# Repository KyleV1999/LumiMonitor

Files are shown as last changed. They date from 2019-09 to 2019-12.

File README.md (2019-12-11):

# PIR Motion Sensor Build Instructions for the LumiMonitor

## Table of Contents
* [Introduction](https://github.com/KyleV1999/LumiMonitor#Introduction)
* [Budget](https://github.com/KyleV1999/LumiMonitor#Budget)
* [Time Commitment](https://github.com/KyleV1999/LumiMonitor#Time-Commitment)
* [Setting Up Your Platform](https://github.com/KyleV1999/LumiMonitor#Setting-Up-Your-Development-Platform)
* [Mechanical Assembly](https://github.com/KyleV1999/LumiMonitor#Mechanical-Assembly)
* [PCB Soldering](https://github.com/KyleV1999/LumiMonitor#PCB-Soldering)
* [Case](https://github.com/KyleV1999/LumiMonitor#Case)
* [Power Up](https://github.com/KyleV1999/LumiMonitor#Power-Up)
* [Production Testing](https://github.com/KyleV1999/LumiMonitor#Production-Testing)

## Introduction

This is the build instructions for building the PIR Motion sensor as part of the LumiMonitor project. The PIR (Passive Infared) Motion Sensor will detect motion within 3 meters of the sensor. These instuction will show you how to design and build the breadboard and PCB circuits to intigrate the sensor with a Broadcom Development Platform (Raspberry Pi 3B+). I will also provide a list of materials and links to where you can buy them, as well as a Corel Draw file so that you can laser cut a case out of clear acrylic. These instutions take into account that you will have access to equipment such as a soldering iron, laser cutter, wire strippers, etc. The PIR Motion Sensor will be used in the final Lumi Monitor project to intiate hands-free data collection. The photo below depicts the final product:

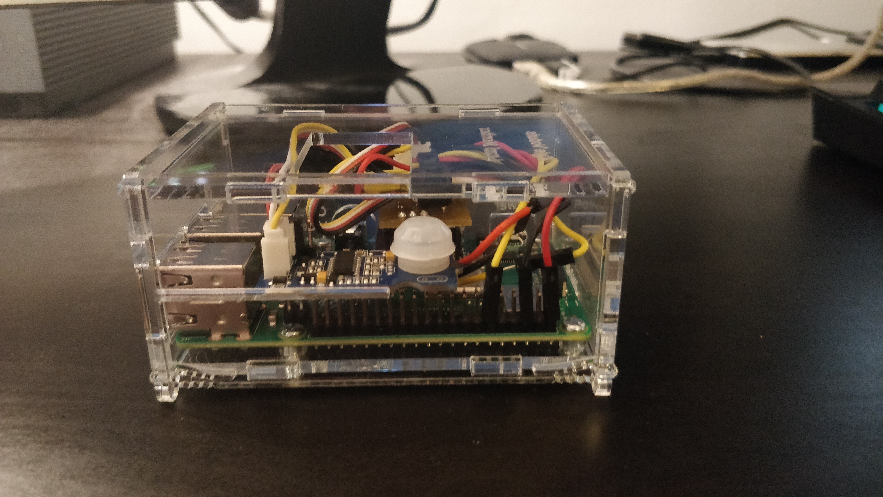
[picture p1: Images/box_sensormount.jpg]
Final Product


### System Diagram

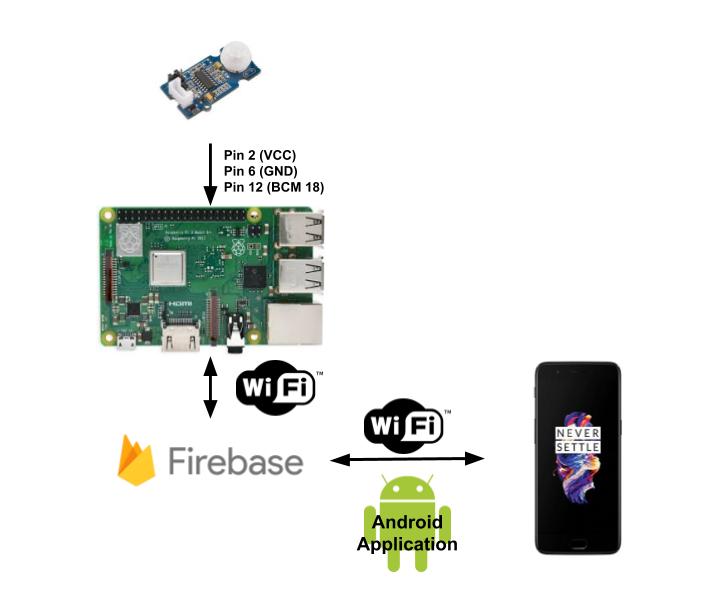
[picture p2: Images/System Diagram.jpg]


Before you begin some skills you will need duing the build of this project include:
* Basic electrical and circuit knowledge
* Basic programming knowledge
  * This project specifically was programmed in Python
* Basic understanding of the Raspberry Pi and Linux based operating systems
* Soldering

## Budget
Thse are the parts needed to complete the project. Displayed below are links and price breakdown for each component.

### Parts for Lumi Monitor

| Part | Source  | Part Number | # of Units | Price Per Unit (CAD)  | Taxes & Shipping (CAD) | Subtotal  | Link |
| --- | --- | --- | --- | --- | --- | --- | ---- |
| Raspberry Pi 3 B+ Motherboard | Amazon | 3BPLUS-R | 1 | $55.97 | $7.28 | $63.25 | https://amzn.to/2kMYDtb |
| Grove ‐ PIR Motion Sensor | Digikey | 101020020 | 1 | $11.56 | $8.35 | $19.91 | https://bit.ly/2kKx8QV | 
| Seeedstudio Grove 4-pin Connector (10) | robotshop.com | RB-See-204 | 1 | $1.33 | $9.01 | $11.67 | https://bit.ly/32it9vh |
| Breakaway PCB Board Header Connector | Amazon | ODYF162934WAZR85384 | 1 | $12.80 | $4.18 | $16.98 | https://amzn.to/37IDlAd |
| Elegoo 120pcs Multicolored Dupont Wire | Amazon | EL-CP-004 | 1 | $11.95 | $4.36 | $16.31 | https://amzn.to/2qHYRop |
| Kingston 32 GB Micro SD Card | Walmart | SDCS/32GBCR | 1 | $11.98 | $2.98 | $14.96 | https://bit.ly/2souG61 / In Store |
| AmazonBasics USB 3.0 to Ethernet Adapter | Amazon | AE3101X1 | 1 | $20.05 | $4.53 | $24.58 | https://amzn.to/2Nwrq0A |
| 3ft Ethernet Cable| PrimeCables.ca | | 1 | $1.24 | $6.88 | $8.12 | https://bit.ly/2QYcxGe |
| Raspberry Pi Micro USB Power Supply | Amazon |DCAR-RSP-2A5 | 1 | $11.99 | $6.36 | $18.35 | https://amzn.to/2skohZp |
| Clear Acrylic Glass 3mm | Amazon | | 1 | $17.09 | $0.00 | $17.09 | https://amzn.to/2XWM1OX |
| M2.5 Screws | Digikey | | 4 | $0.15 | $0.00 | $0.60 | https://bit.ly/2Oy8TS9 |
| Lead Free Solder | Amazon | 2-CA-X | 1 | $15.99 | $4.32 | $20.31 | https://amzn.to/37JXLJj |
| **Total Cost** | **$232.13** |
| **Total Tax & Shipping** | **$58.25** | 

It would also be a good idea to have your PCB made and your case laser cut before you start your project. Use this [fritzing file](Electronics/LumiMonitor_MotionSensor2.fzz) to generate your gerber file and this [corel draw](Mechanical/KylePi2CaseX6.cdr) file to have your case cut.

Here is the link to [seeedstudio.com/](https://www.seeedstudio.com/fusion_pcb.html) where you can upload your gerber file  to have your PCB made. It is $3.92USD ($5.19 CAD) for 10 PCBs.

**Below is an image that contains all the major parts for the project; The Grove PIR Motion Sensor, Raspberry Pi 3B+ and Grove Sockets.**

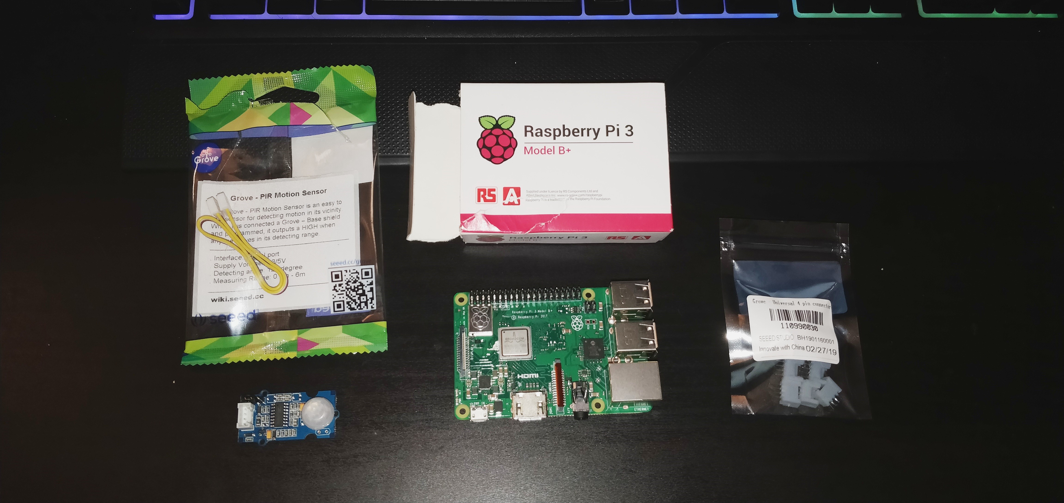
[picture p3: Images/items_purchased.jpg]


## Time Commitment

When I put together this project, I did it in a period of 14 weeks. The schedual that I followed to complete the project is shown below. However, this project can most likely be done in the matter of a weekend, granted that all the parts needed have been delivered, you have your PCB made and that you have access to all the required equipment needed to complete the project.

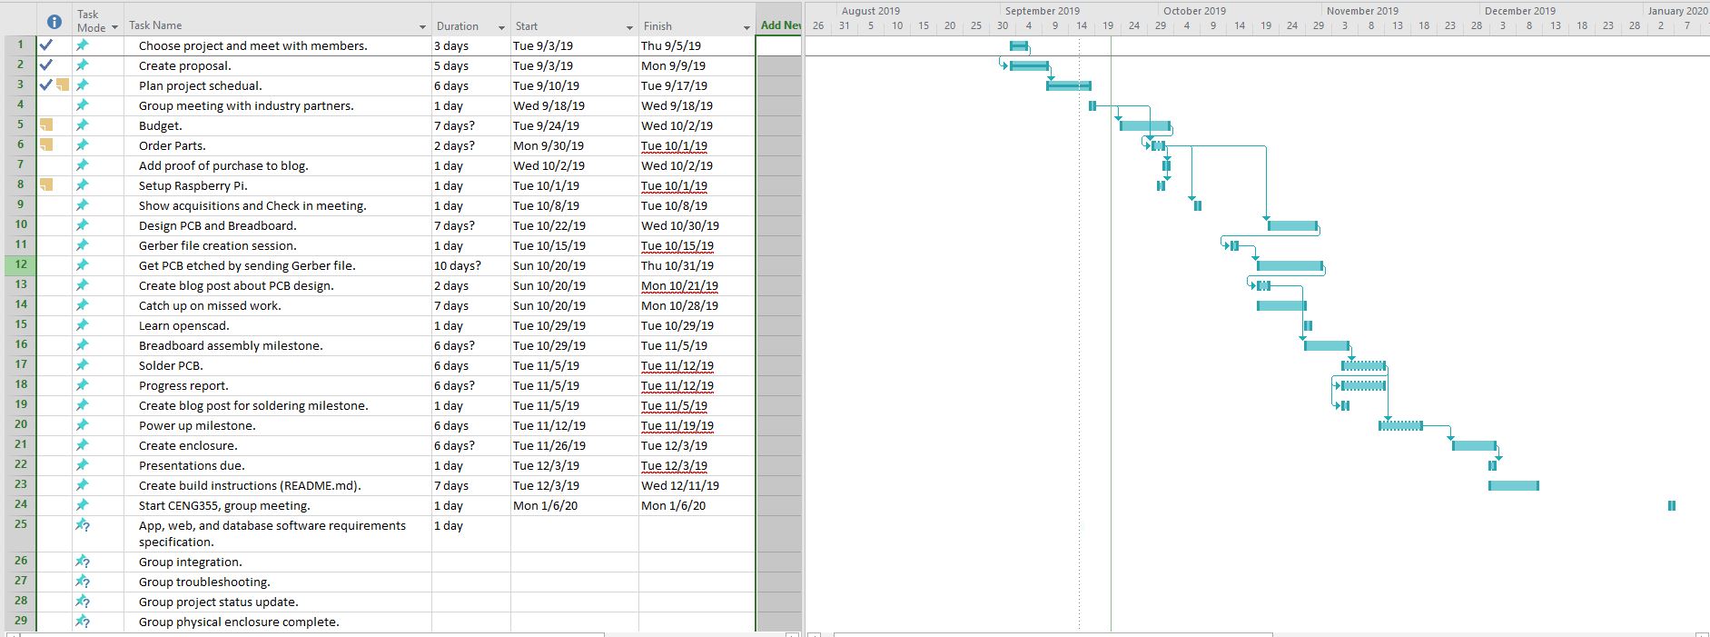
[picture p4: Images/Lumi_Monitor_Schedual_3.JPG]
Schedual


**Estimate Time:**

* Setting up your development platform - 45 Minutes
* Breadboard Assembly & Testing - 25 Minutes
* PCB Soldering - 30 Minutes
* PCB Powerup - 5 Minutes
* Laser Cut Case - 20 Minutes
* Assemble Case w/ Development Platform & Sensor - 25 Minutes
* Final Testing & Troubleshooting - 20 Minutes

**Total Estimated Time: 170 Minutes or 2 Hours and 50 Minutes**

## Setting Up Your Development Platform
The very first step of the project would be to setup your Raspberry Pi 3B+ with the latest kernal of Raspian. If you are new to Raspberry Pi's, I would reccommend doing this through NOOBS (New Out Of the Box Software) operating system installer. I've made this tutorial video on how to do this: [How To Install NOOBS Onto A Raspberry Pi (3B+/4)](https://youtu.be/TlQxaEdyBgM).

### Setting Up SSH

Once your Raspberry Pi has been configured with an operating system, remote desktop and SSH should be configured so that you can connect to the Pi through USB to Ethernet rather than displaying the Pi on a external display through an HDMI cable. 

To setup SSH, begin by opening the terminal by pressing CTRL+ALT+T on the keyboard. Next, use the command ```sudo raspi-config```. An interface similar to as show below should appear. Using the up and down arrow keys select interfacing options and press ENTER.

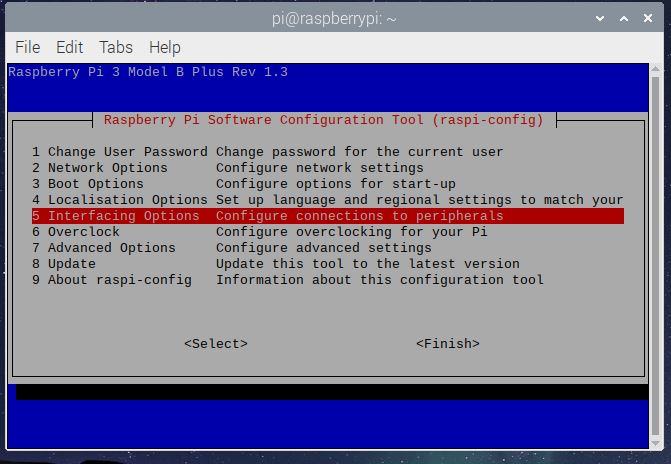
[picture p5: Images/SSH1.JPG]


Next, use the up and down arrow keys to select SSH and hit enter.

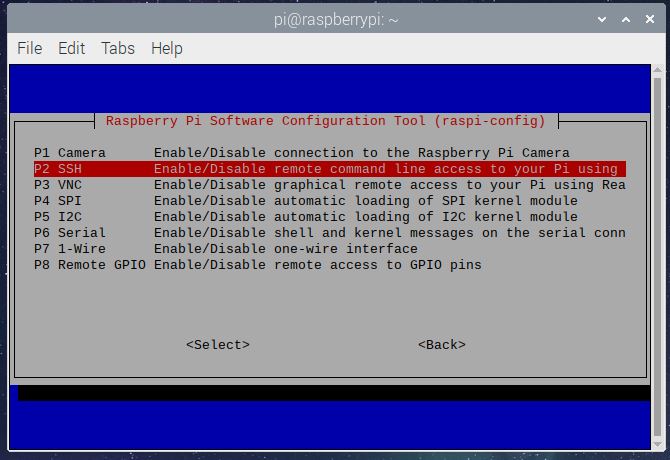
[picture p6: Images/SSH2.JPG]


Finally, using the right and left arrow keys select Yes. SSH has now been successfully enabled.

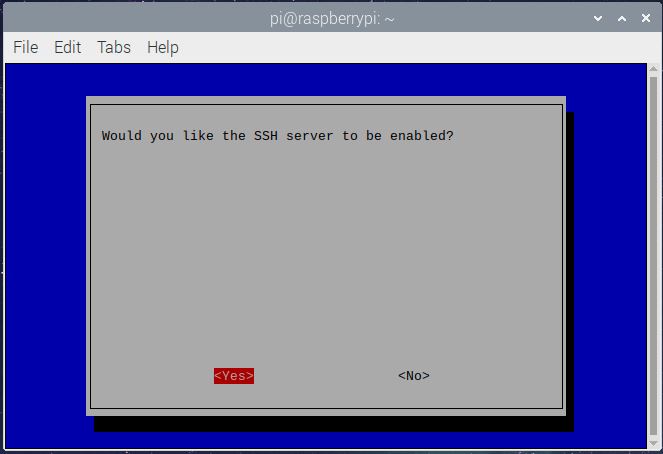
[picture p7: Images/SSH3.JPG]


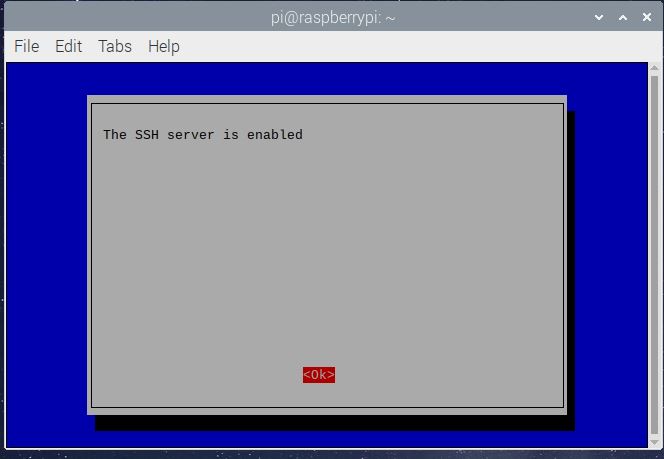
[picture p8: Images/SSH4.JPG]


Now, plug in one end of the ethernet cable into the Raspberry Pi and the other end into the adapter. Plug the USB end of the adapter into a PC. Next use the ```ifconfig``` command to retrieve the IPv4 address of the Pi's ethernet interface. In my case it is 169.254.123.117.

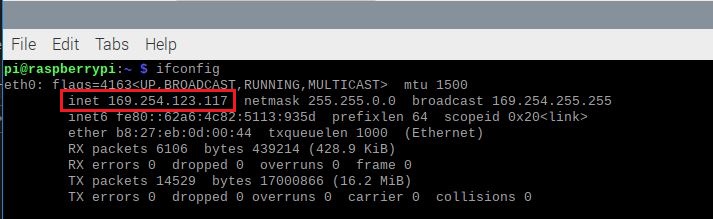
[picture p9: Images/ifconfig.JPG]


Now use and SSH client like [PuTTY](https://www.chiark.greenend.org.uk/~sgtatham/putty/latest.html). Enter the IPv4 address then press open. You should be prompted with a login. Enter your Pi's username and password. Finally, you should be able to control the terminal of your Raspberry Pi through SSH.

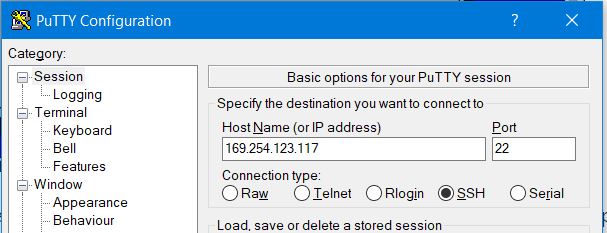
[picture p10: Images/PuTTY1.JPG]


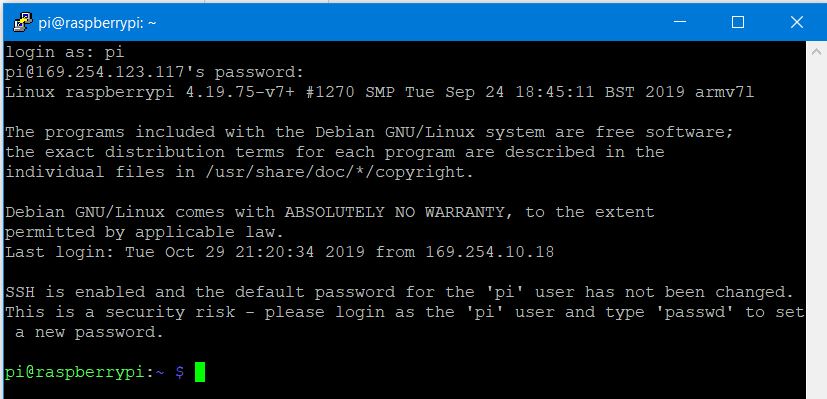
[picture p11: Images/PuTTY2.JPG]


### Setting Up Remote Desktop
To enable remote desktop to connect and control the Raspberry Pi with a graphical user interface, open up the terminal on the Pi and enter the following commands:

```sudo apt-get install tightvncserver```

```sudo apt-get install xrdp```

After that make sure that your Raspberry Pi is connected to a PC with the ethernet cable and USB to ethernet adapter. Now open "Remote Desktop" on the PC and put in the IPv4 address found earlier and click connect. Enter your Pi's login information and finally, you should be in the remote desktop environment.

<img src="Images/RD1.PNG" align="center">

<img src="Images/RD2.PNG" width="720" height="400" align="center">

<img src="Images/RD3.PNG" width="720" height="500" align="center">

## Mechanical Assembly
Now that your development platform has been setup, you should have your PCB made. Provided below are two [fritzing](https://fritzing.org/home/) files:

[Fritzing File With Development Platform](Electronics/LumiMonitor_MotionSensor.fzz)

[Fritzing File With Headers](LumiMonitor_MotionSensor2.fzz)

[Fritzing File With Development Platform](Electronics/LumiMonitor_MotionSensor.fzz) is the breadboard pictorial, schematic diagaram and PCB diagram that describes the connection between the sensor and the development platform. [Fritzing File With Headers](LumiMonitor_MotionSensor2.fzz) shows the connections with the header. Use this file to generate a Gerber file which is to be used to make your PCB.

Before you start soldering the PCB, it would be a good idea to test out that your components and development platform are functioning correctly by building the circuit on a breadboard. Below is and image of the breadboard pictorial and schematic diagram of the circuit.

![Breadboard](Images/LumiMonitor_MotionSensor_bb.jpg)

<img src="Images/LumiMonitor_MotionSensor_schem.jpg" width="720" height="500" align="center">

One thing to keep in mind when breadboarding is that the pins on the Grove socket, for the motion sensor, are too close together to fit on the breadboard. To get around this, stick wires directly into the header of the sensor's wire, then place each wire individually onto the breadboard. 

* Pin 2 (5V) of the Raspberry Pi should be connected to the positive side of the breadboard.
* Pin 6 (GND) of the Raspberry Pi should be connected to the negative side of the breadboard.
* The red (VCC) wire from the motion sensor should be connected to the positive side of the breadboard.
* The black (GND) wire from the motion sensor should be connected to the negativeside of the breadboard.
* The yellow (D1) wire from the motion sensor should be connected to breadboard.
* Pin 12 (BCM 18) of the Raspberry Pi should be connected to the D1 from the sensor on the breadboard.

[pinout.xyz](https://pinout.xyz/) is a good reference for the Raspberry Pi's pin layout. When you finish breadboarding, it should look something like the image below.

![Breadboard](Images/breadboard1.jpg)

Now test to see if the motion sensor is working. [Upload this code to your Pi](Software/motion.py). This is a Python script which will detect HIGH (if motion is detected) and LOW (if no motion is detected). To run the code, open the terminal and make sure that you are in the same directory as your code. Use the command ```python motion.py``` to run the script. If motion is detected, "Motion detected" should be printed out on the screen. If no motion is detected then "No motion detected" is printed. When the sensor detects motion it will stay in a HIGH state for 1 second.

<img src="Images/ScreenCapture2.JPG" width="720" height="400" align="center">

## PCB Soldering

If this is your first time soldering, I would recommend that you watch this tutorial before you begin: [Beginner how to Solder](https://www.youtube.com/watch?v=oqV2xU1fee8). Below is a PCB Diagram from fitzing along with images of the front and back sides of the PCB before anything is soldered.

<img src="Images/LumiMonitor_MotionSensor_pcb2.jpg" align="center">

### Front of PCB
<img src="Images/pcb_front_cropped.jpg" width="720" height="480" align="center">

### Back of PCB
<img src="Images/pcb_back_cropped.jpg" width="720" height="480" align="center">

1. The first step in soldering the PCB would be to solder the female header. For this project you only need three sockets to connect to the Pi. Before soldering cut the longer header into three sockets with an exacto knife. The pins of the header should be soldered facing the front of the PCB.

1. Next, Solder the Grove socket to the PCB. The pins of the socket should be facing the bottom on the PCB.

1. Finally, you will need to solder the via's / through holes to connect the front side of the board to the back. This can be done by stripping a wire and applying solder to both sides of the hole. 

An example of the final product is shown below:

### Front

<img src="Images/pcb_front_soldered_cropped.jpg" width="750" height="750" align="center">

### Back

<img src="Images/pcb_back_soldered.jpg" width="600" height="1000" align="center">

### With Sensor Connected

<img src="Images/pcb_soldered_sensor_cropped.jpg" width="800" height="550" align="center">

## Case

Here is a link to the [Corel Draw](Mechanical/KylePi2CaseX6.cdr) file that will be used to lase cut the case. This is a modified design from which the original design can be found [here](https://github.com/diy-electronics/raspberrypi-b-plus-case).

Two slits were made, which is used to slide in the PCB and sensor to keep them in place. A window was also placed a the top to make it easier for the sensor to detect motion. There are screw holes at the bottom of the case to keep the development platform in place and all I/O are accessable.

<img src="Images/box_top_cropped.jpg" width="800" height="600" align="center">

## Power Up

Before you enclose your PCB and sensor into the case, It would be a good idea to power it up to see if your PCB soldering was successful. It is easier to do this outside of the case to make adjustments if needed. Plug the VCC, GND and D1 wires from the female socket on the PCB intro their correct pins on the Raspberry Pi and and plug the sensor into it's socket. Power up the Raspberry Pi and connect to it via SSH. Run the same code from before with the command ```python motion.py```. If everything is working correctly then "Motion Detected" will be displayed when motion is detected. **Warning do not leave the powered up project unattended just in case something goes wrong!** Finally, Once everything has been testedd and is working correctly, enclose you project in the case.

## Production Testing
When testing in a production environment, a PCB should be made for testing the sensor. This is because the dedicated socket for my sensor will not fit on a breadboard and it's simpiler and quicker to just plug the sensor into the socket to test it. Also a dedicated Raspbarry Pi with the all the software installed should be on hand. This is so any PCB or sensor can be swiftly connected, and tested in a matter of a few minutes.   

[Back To Top](https://github.com/KyleV1999/LumiMonitor#pir-motion-sensor-build-instructions-for-the-lumimonitor)

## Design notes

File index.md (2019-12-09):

<html>
<center><h1>Blog For CENG 317 - Lumi Monitor</h1></center>
	
<h2>Build Instructions - 10/12/2019</h2>
<p>Build instuctions for project are complete. <a href="https://github.com/KyleV1999/LumiMonitor/blob/master/README.md">Can be viewed here.</a></p>
	
<h2>Presentation - 25/11/2019</h2>
<p>The final presentation was due this week. <a href="Documentation/Lumi Monitor – PIR Motion Sensor.pptx">Here is a link to the slides from my repository.</a></p>
	
<h2>Enclosure - 18/11/2019</h2>
<p>Over the pass few days I have designed, laser cut and put together an enclosure, that is made out of clear acrylic, to incase my Raspberry Pi, PCB and sensor securely. I decided to use laser cutting to create my enclosure over 3D printing due to time constraints and designing a box for laser cutting is slightly easier. There were a few problems that I encountered while going though the process of making the enclousure. First of which was my lack of knowledge and skill in design. Since this was my first time doing a design project like this, I had to take some time to learn the design software (Corel Draw) and figure out how I was going to make my design so that it can incase all my components as securly as possible. I went to the Prototype Lab for help and the technologists suggested that I make modifications to an already made design. The original design can be found <a href="https://github.com/diy-electronics/raspberrypi-b-plus-case"><u>here</u></a>. This desgin is under a creative commons license therefore it can be used for free as long as credit is given to the original creator. The CC license is etched onto the bottom of the box. The second problem I ran into was the high demand for the laser cutter. It was hard to work around my schedule when the cutter was free. The demand was high due to the amount of final projects being cut on the cutter. Also the other laser cutters in the college have broken down, so the only laser cutter available was the one in the prototype lab, that was under high use. The changes that I made to the orignal case design was adding two slits on the side on the enclosure to slide my PCB and Sensor into to hold them in place. The height of the slits were mesaure as the same as the PCB's. This idea worked very well dispite what I originally thought and the PCB and sensor are securely in place. The next modification I made was making a hole at the top of the case so that my sensor can detect motion without the acrylic being in the way. Once the case was together I secured all wires with a zip tie and put them off to the side. The project is a few days ahead of schedule and no further additions to the budget have been made. The enclousure was one of the final big milestones for this term. The next step is to work on the Prototype Acceptance Presentation.</p> <a href="Mechanical/KylePi2CaseX6.cdr"><u>Here is a link to the corel draw file for my design.</u></a>
<br><br>
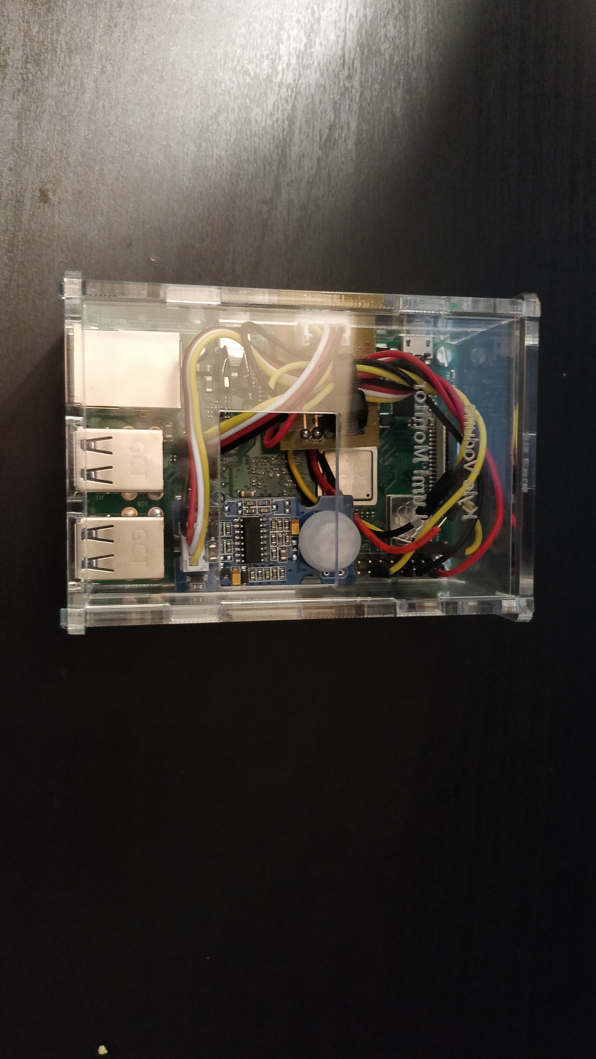
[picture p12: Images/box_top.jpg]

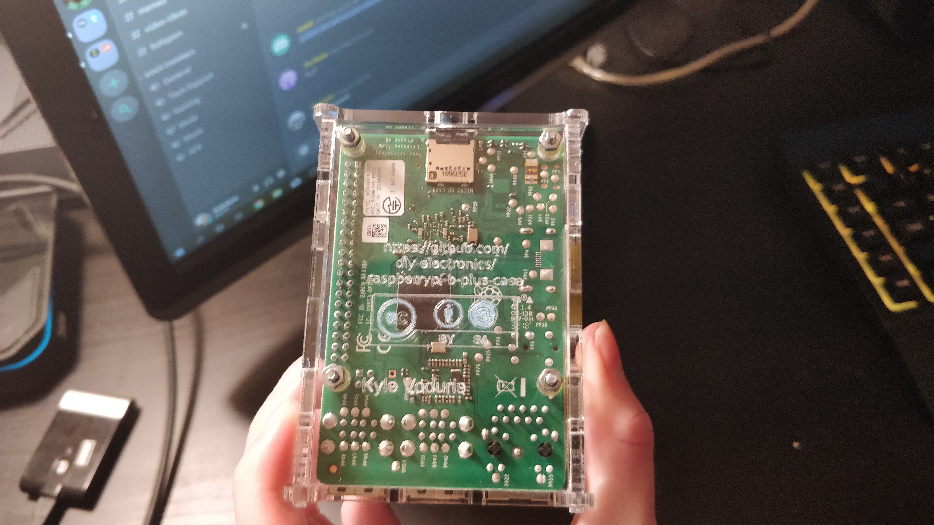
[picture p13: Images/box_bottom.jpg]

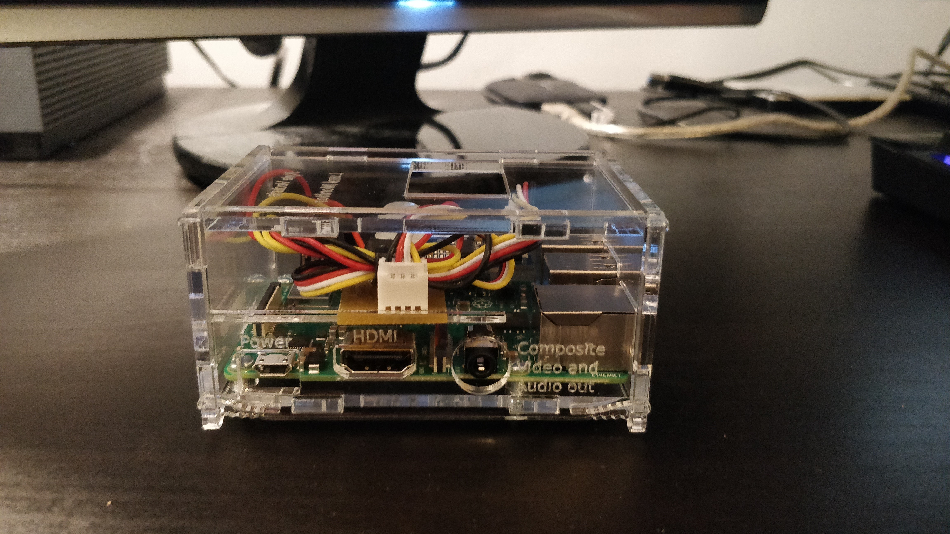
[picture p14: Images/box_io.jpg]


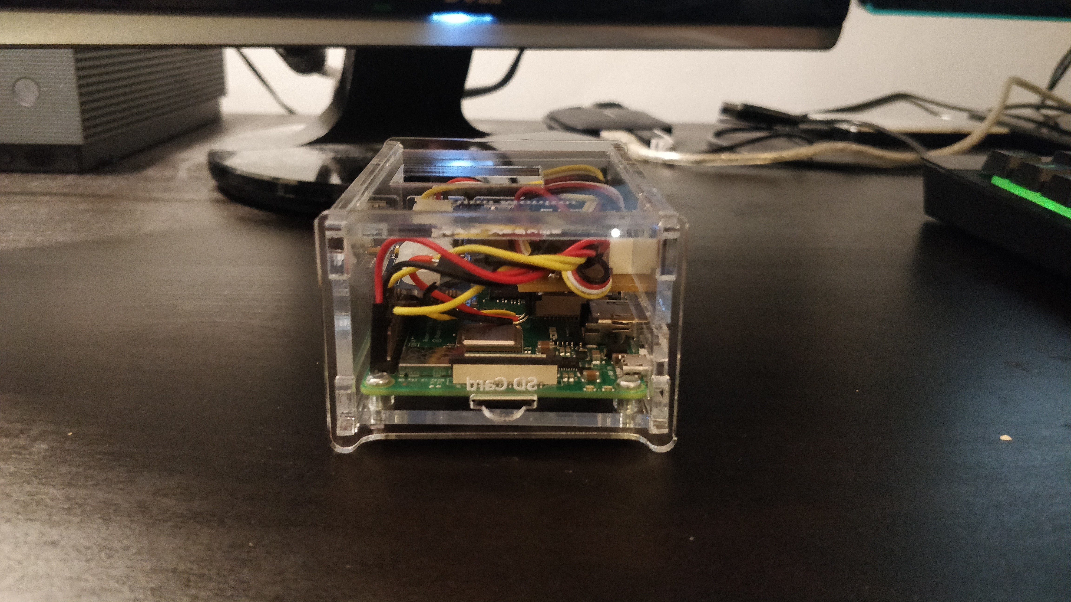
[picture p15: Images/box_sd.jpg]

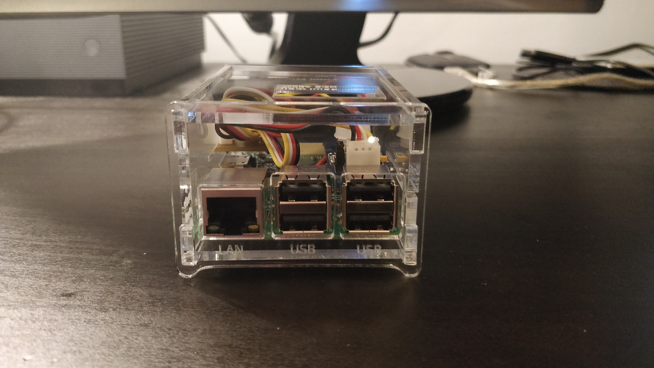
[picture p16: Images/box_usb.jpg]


<h2>PCB Powerup - 12/11/2019</h2>
<p>During the lab, I powered up my PCB for the first time to see if it will work. I plugged the sockets from the PCB onto the pins on the Raspberry Pi and plugged my motion sensor onto the PCB. I ran the test code on the Pi and it detected when there was motion or not correctly.The project is on track in terms of time and there are no further additions to the budget. I am now working on creating an enclosure for the Pi,sensor and PCB.</p>
<br>
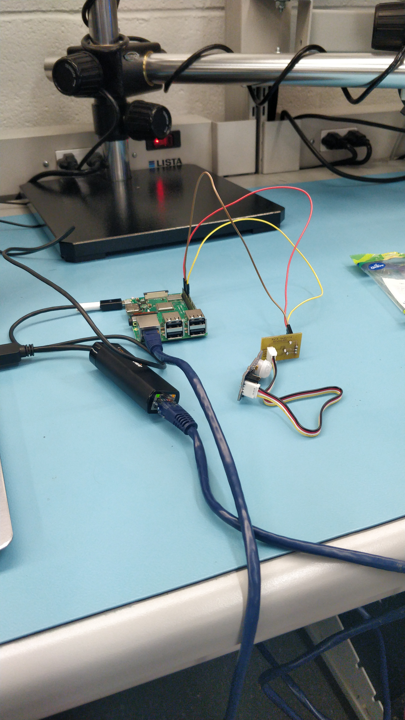
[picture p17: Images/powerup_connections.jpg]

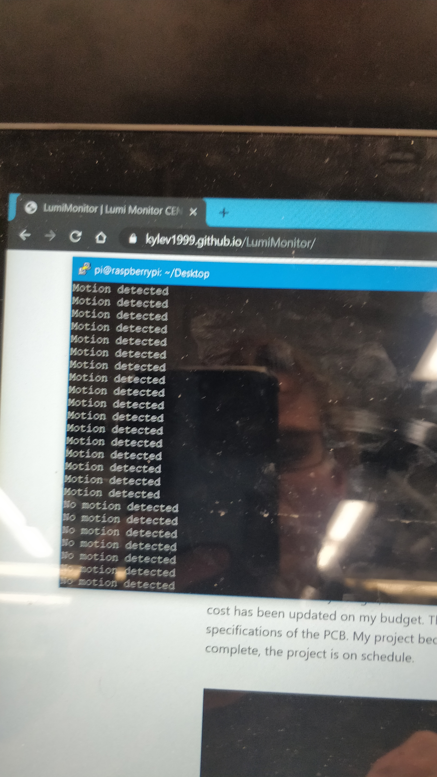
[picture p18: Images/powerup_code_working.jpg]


<h2>PCB Soldered - 09/11/2019</h2>
<p>This week I soldered sockets onto my PCB board so that I can connect my sensor to it and so that the board can connect to the Raspberry Pi. I also solderd wires into the through-holes to connect the top side of the board to the bottom. During the process of soldering I ran into a few issues. The first issue I ran into was I mistakenly soldered both of the sockets to the wrong side of the PCB. I used the desoldering pump to re-solder my sockets correctly. However when I went to check the board by using a multi-meter the resistance showed overloaded, meaning something is wrong with the connections on the board. The connections seemed correct and soldered properly with no shorts; I believe I may have damaged my board during the proccess of desoldering and resoldering. I decided to print another board and tried to solder again. The process on soldering the second board went smoothly and the multi-meter showed proper results. In terms of my budget, I ordered and recieved my USB to Ethernet Adapter from Amazon so that I can easily SSH into my Pi. The cost has been updated on my budget. The Female Header Connector was provied from the prototype lab and cut down fit the specifications of the PCB. My project became slightly off track when I had to print and solder another PCB, but now that this step is complete, the project is on schedule.</p>  
<br>
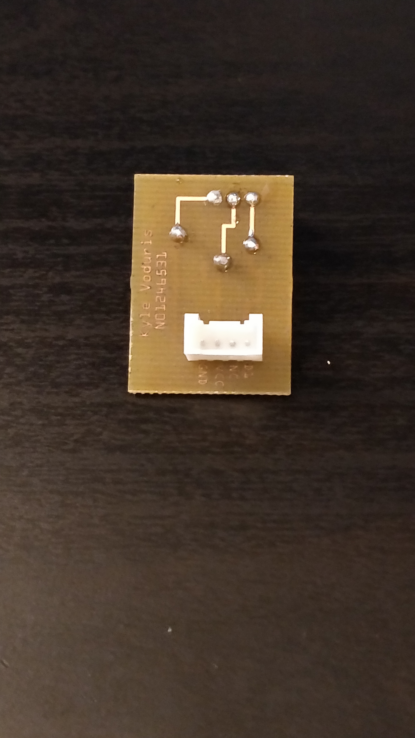
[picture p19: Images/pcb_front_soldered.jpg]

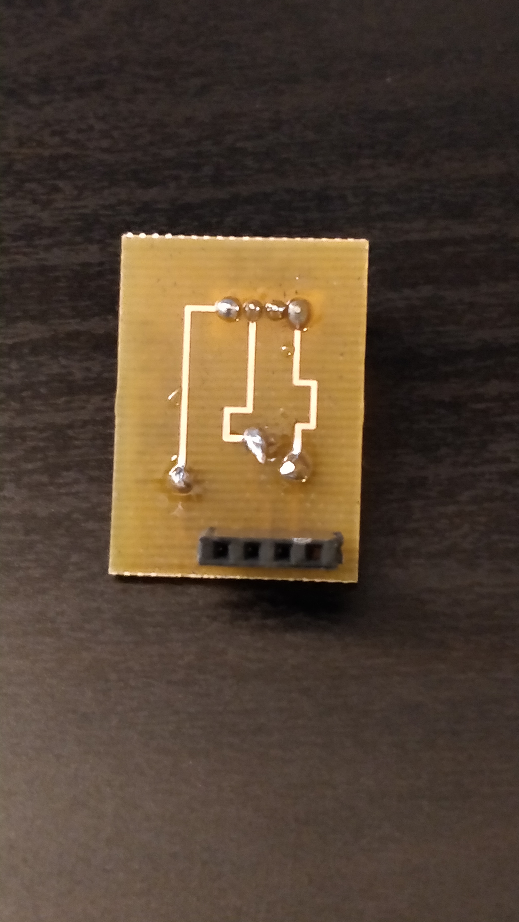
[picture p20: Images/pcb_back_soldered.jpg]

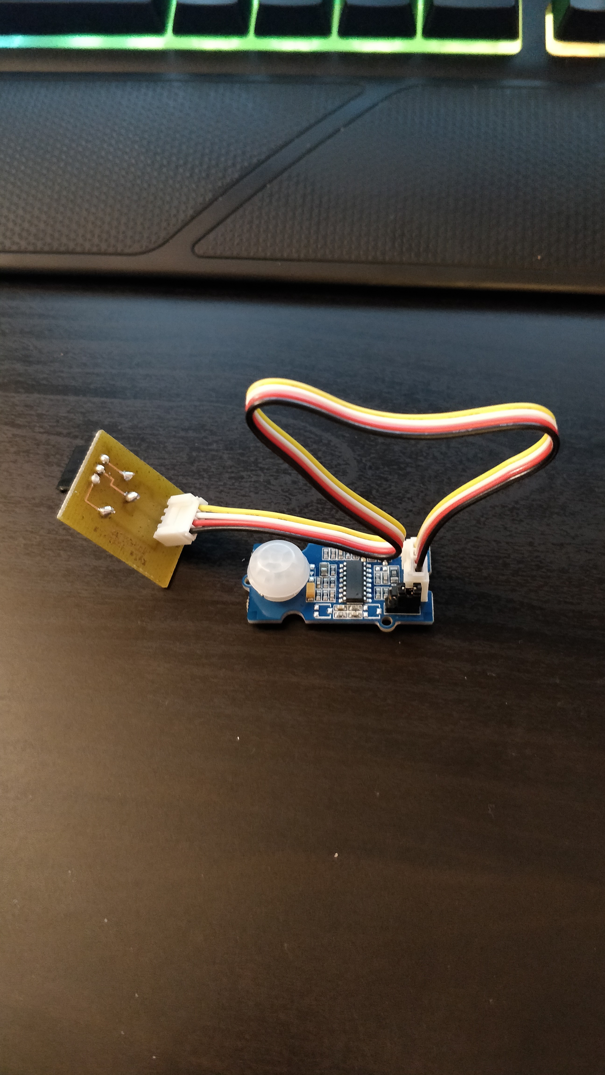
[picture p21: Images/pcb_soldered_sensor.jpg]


<h2>Breadboard Milestone - 30/10/2019</h2>
<p>This week I put my breadboard design into fruition by wiring up my PIR motion sensor to my Raspberry Pi. The process of wiring went smoothly, however I had trouble getting my sensor to work on the Raspberry Pi. I decided to write my test code out in Python. I chose to use Python due to its simplicity and compatiblity with the Pi. The problem was, I have a lesser knowledge in Python so I had some trouble getting the program up and running, therefore putting the project a day behind. I was able to get two Python programs working to demonstrate the funtionality of my motion sensor. The first program I made checks each iteration of the loop to see if the output on the sensor is HIGH or LOW. The problem with this code was that the IDE I was using to compile the code had trouble keeping up with the output and did no display the results properly. When the code was ran though the terminal it worked fine. The second code slows this down so it only checks the sensor output every 0.1 seconds. The two programs can be found here:
<a href="Software/motion.py">motion.py</a>, <a href="Software/motion2.py">motion2.py</a>.</p>
<br>
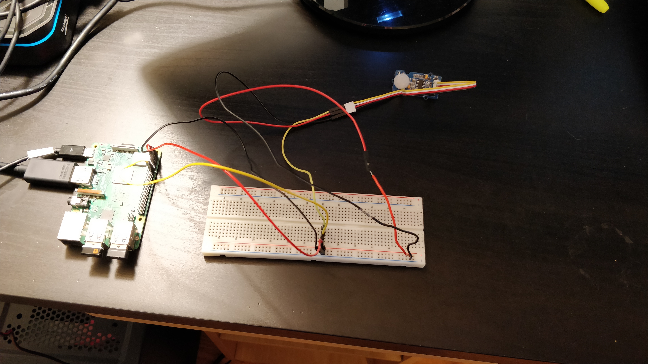
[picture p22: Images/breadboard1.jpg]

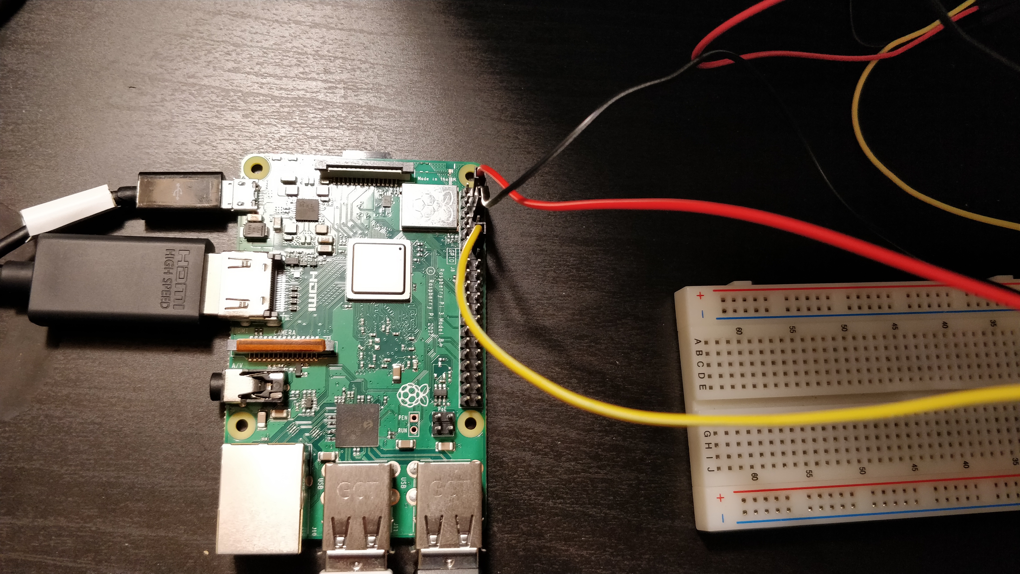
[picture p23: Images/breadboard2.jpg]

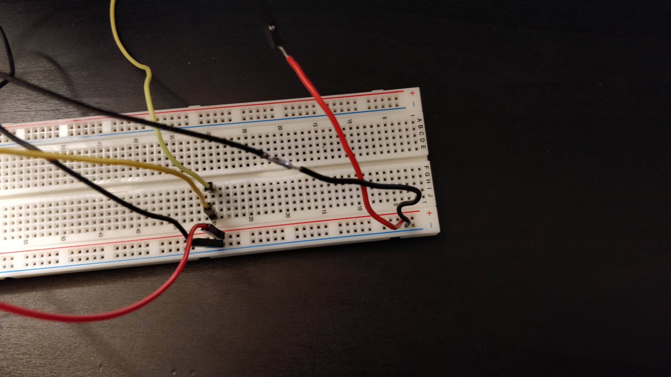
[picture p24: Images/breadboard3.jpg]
 
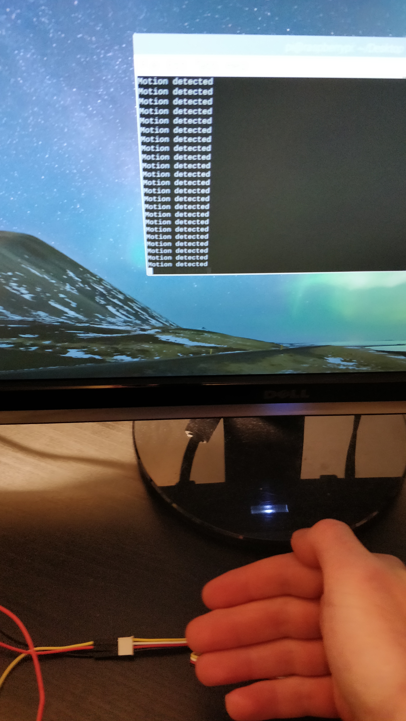
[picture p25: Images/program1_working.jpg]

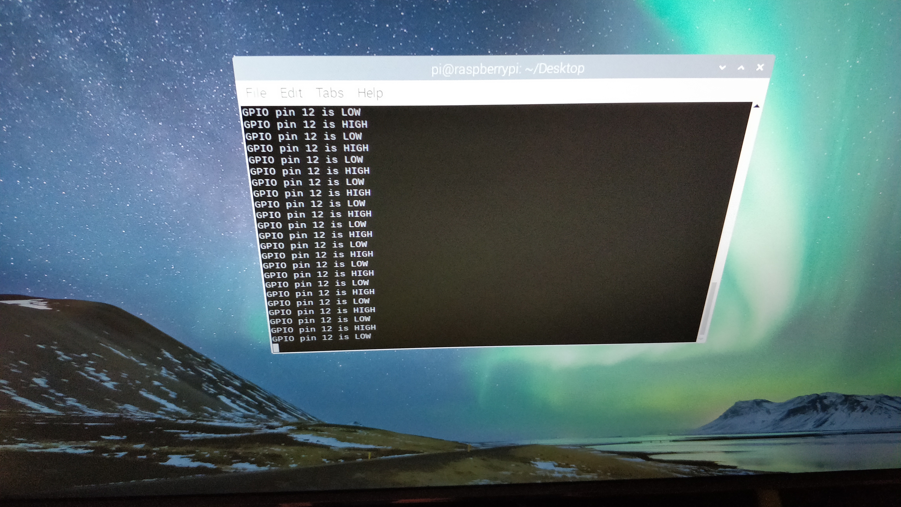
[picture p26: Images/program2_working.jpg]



<p>I also sent my gerber files to the prototype lab to get my PCB made. I got my PCB made twice since I made some minor adjustments to the wires on the board. Now that I've completed the breadboard milestone my project is now back on track with project schedule. In terms of the budget, I've had to add more costs. Like mentioned in the previous post, I had to buy sockets to connect my motion sensor to the PCB. I will also need to purchase a USB to ethernet adapter so that I can SSH into my Raspberry Pi from my laptop. I tried to save money on the budget by skipping out on this, since I thought that the monitors in the lab had an HDMI port to display the Pi. I will add the cost to the budget when I order it.</p>
<br>
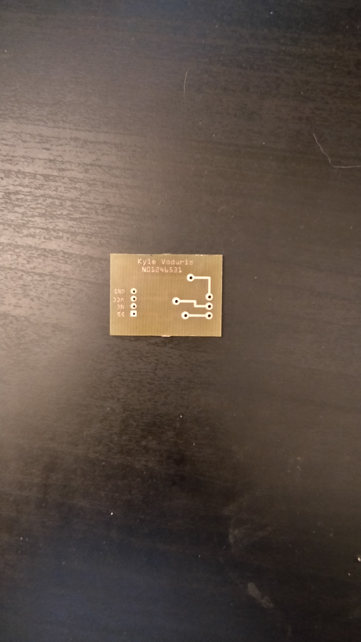
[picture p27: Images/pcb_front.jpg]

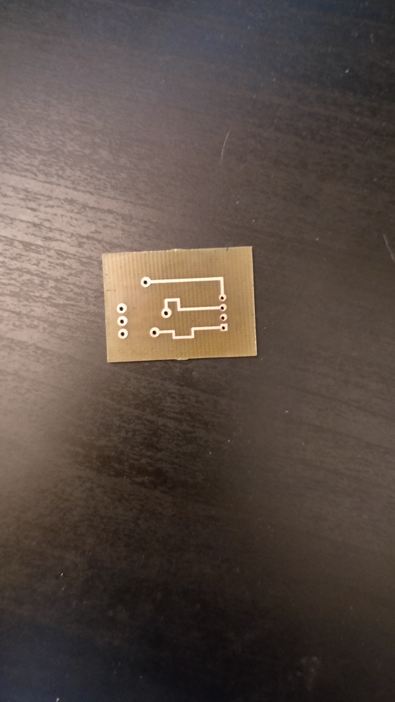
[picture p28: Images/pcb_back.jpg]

	
<h2>Breadboard and PCB Design - 15/10/2019</h2>
<p>Designed the breadboad and PCB for the Grove PIR Motion Sensor. Fritzing did not have the Grove PIR Motion sensor
included in the list of parts; I couldn't find a PIR Motion Sensor Part with 4 Pins online either. Instead, for the                     diagrams I used the Grove Light Sensor. It has the exact same pin layout as the Motion Sensor using the same connector. I was able
to edit the breadboard view in a program called InkScape to represent the motion sensor better.</p>
		
<h3>Breadboard</h3>
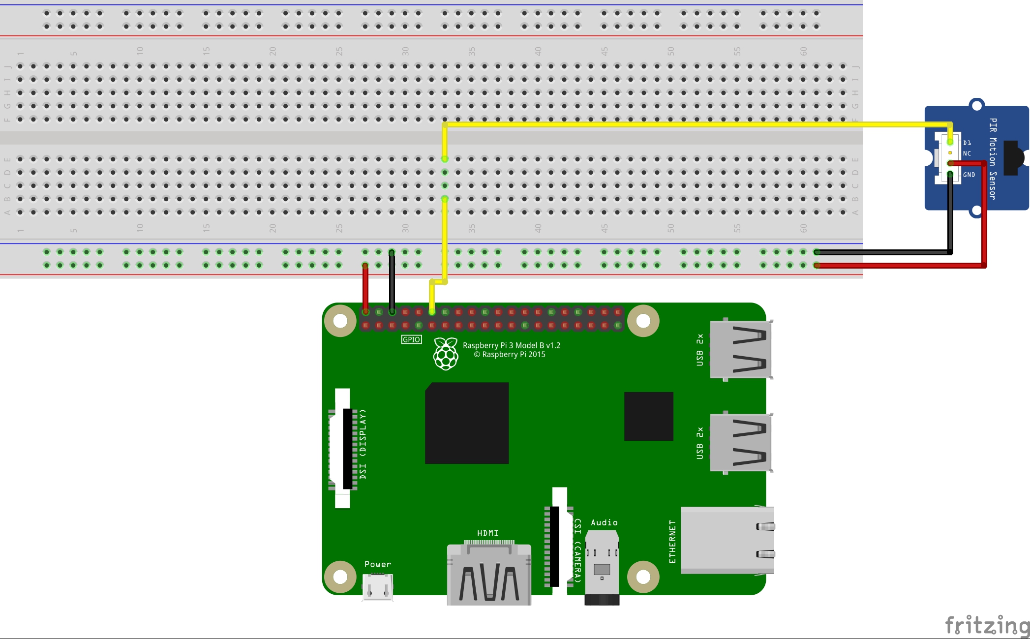
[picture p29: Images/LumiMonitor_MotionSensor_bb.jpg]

<br>
<h3>Schematic</h3>
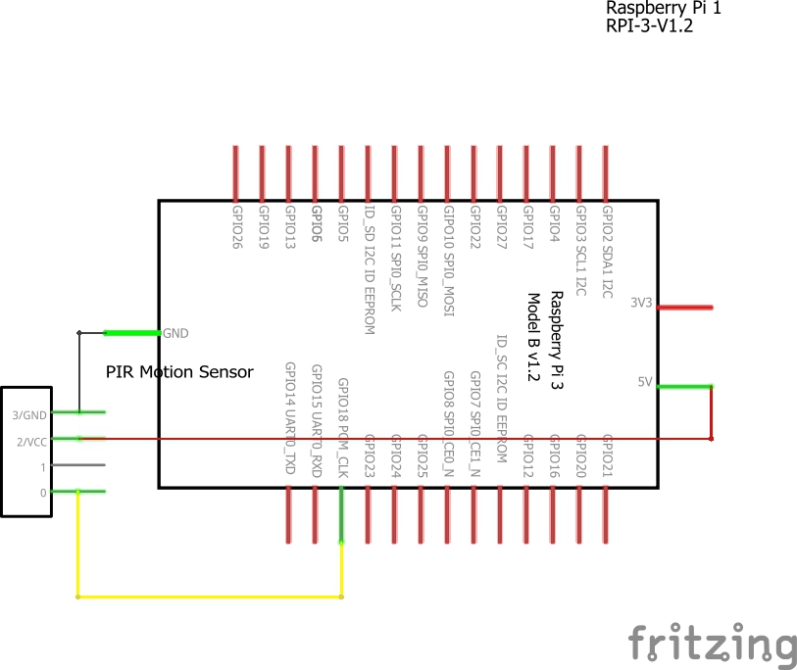
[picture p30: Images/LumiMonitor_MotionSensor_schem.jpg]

<br>
<h3>PCB</h3>
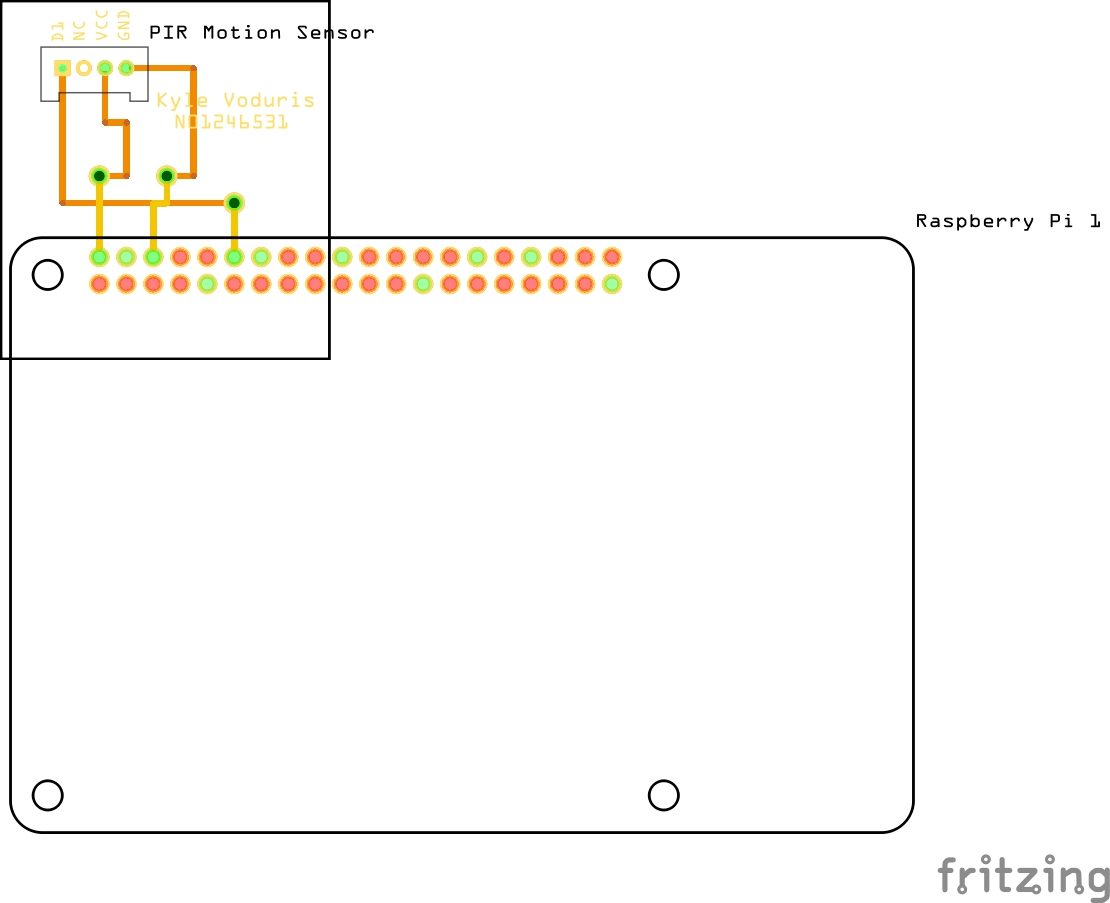
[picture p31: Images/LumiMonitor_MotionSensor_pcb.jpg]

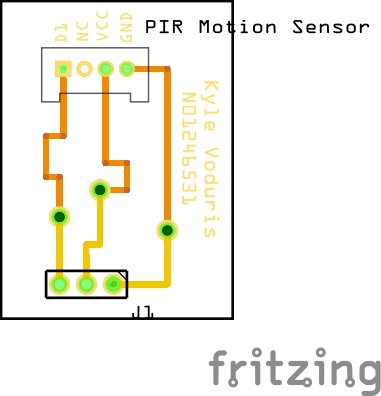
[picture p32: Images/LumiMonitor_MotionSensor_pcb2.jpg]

<br>
<h3>Fritzing Files</h3>
<p><a href="https://github.com/KyleV1999/LumiMonitor/blob/master/Electronics/LumiMonitor_MotionSensor.fzz">Fritzing File1</a><br>
<a href="https://github.com/KyleV1999/LumiMonitor/blob/master/Electronics/LumiMonitor_MotionSensor2.fzz">Fritzing File2</a>
</p>

<h2> Additonal Purchase & Recieve Products - 8/10/2019</h2>
<p>The items that I purchased below were delivered. I setup the Raspberry Pi with an operating system. In this case
Raspian with kernal 4.19, installed on my 32GB micro SD card. I also configured SSH and VNC viewer so I can connect and control the     Pi remotely. I also forgot to purchase a socket for my motion sensor so that it can connect to the PCB. I puchased 10 <a href           ="https://bit.ly/32it9vh"><u>Seeedstudio Grove 4-pin Connectors</u></a></p>


		
<br>.

<h2>Purchases - 29/09/2019</h2>
<p>Purchased <a href="https://bit.ly/2kKx8QV"><u>Grove PIR Motion Sensor</u></a> and <a href="https://amzn.to/2kMYDtb"><u>Raspberry Pi 3 B+ Motherboard</u></a></p>
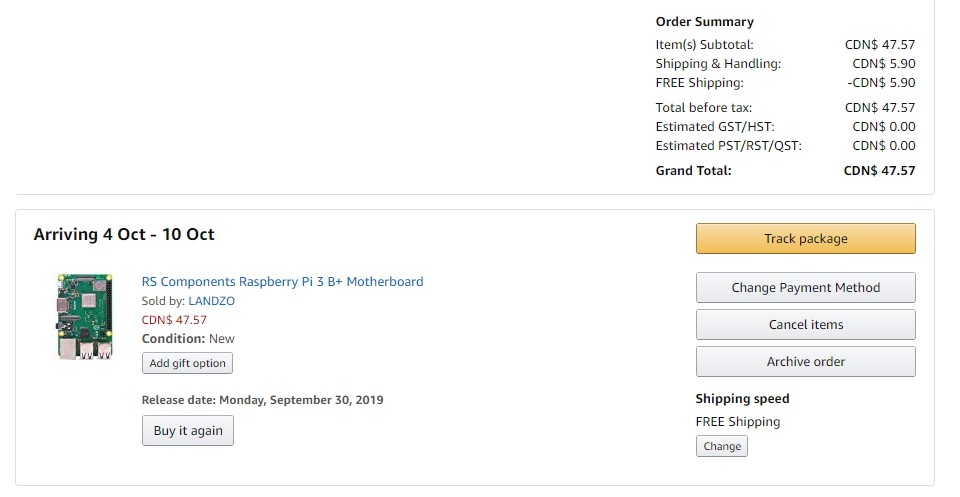
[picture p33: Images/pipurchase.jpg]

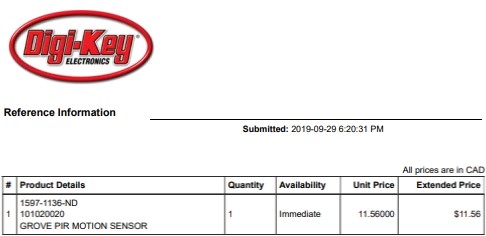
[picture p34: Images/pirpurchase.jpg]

		
<h2>Created Budget and Met With Collaborator - 24/09/2019</h2>
<p>Today my group and I met with our industry collaborator here at Humber College. He agreed with our ideas to design the Lumi monitor into a mobile. He also agreed with the sensors we are using and gave me the idea to use my motion sensor to record hands free feeding data. Finally he showed us a previous prototype of the Lumi Monitor. Our group decided to use the Raspberry Pi as a development platform. My group also came up with an individual budget for our project which can be found <a href="https://github.com/KyleV1999/LumiMonitor/blob/master/Documentation/Lumi%20Monitor%20Budget.pdf"><u>here</u></a>.	</p>
				
<h2>Constructed Project Plan and Schedule - 17/09/2019</h2>
<p> <a href="https://github.com/KyleV1999/LumiMonitor/blob/master/Documentation/Project%20Schedual.pdf"><u>Detailed Schedule Here</u></a><br>This is an estimated schedule / time frame my group will try to stick to when developing the Lumi Monitor over the next two semesters.</p>
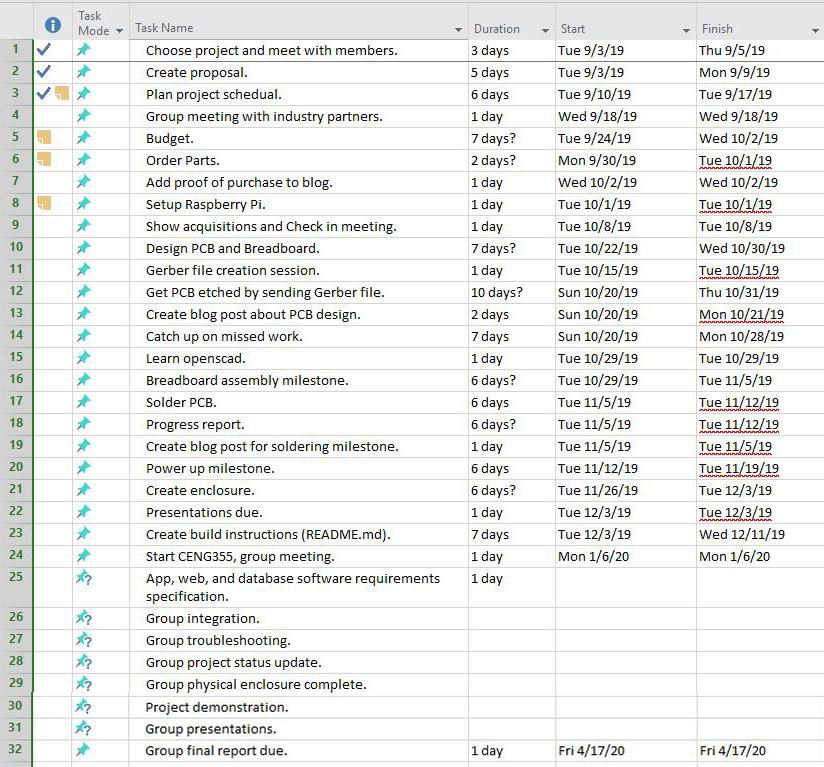
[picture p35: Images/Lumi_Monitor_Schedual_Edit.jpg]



<h2>Hardware Proposal - 10/09/2019</h2>
<p>	This is the original proposal for our project. This outlines our original ideas for the project, project background and infromation about the sensors we plan to use:
		<br><a href="https://github.com/KyleV1999/LumiMonitor/blob/master/Documentation/ProposalContentKyleVodurisRev03.pdf"><u>Project Proposal Content</u>
		<br><a href="https://github.com/KyleV1999/LumiMonitor/blob/master/Documentation/ProjectProposalKyleVodurisRev03.pdf">
	<u>Project Proposal</u></a></p>
				
<h2>Repository Created - 05/09/2019</h2>
<p><a href="https://github.com/KyleV1999/LumiMonitor"><u>https://github.com/KyleV1999/LumiMonitor</u></a></p>

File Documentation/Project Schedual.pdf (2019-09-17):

Task; Mode; Task Name; Duration; Start; Finish; Create proposal.; 5 days; Tue 9/3/19; Mon 9/9/19; Plan project schedual.; 6 days; Tue 9/10/19; Tue 9/17/19; Group meeting with industry partners.; 1 day; Wed 9/18/19; Budget.; 7 days?; Tue 9/24/19; Wed 10/2/19; Order Parts.; 2 days?; Mon 9/30/19; Tue 10/1/19; Setup Raspberry Pi.; Design PCB and Breadboard.; Tue 10/22/19; Wed 10/30/19; Gerber file creation session.; Tue 10/15/19; Catch up on missed work.; 7 days; Sun 10/20/19; Mon 10/28/19; Learn openscad.; Tue 10/29/19; Breadboard assembly milestone.; 6 days?; Tue 11/5/19; Solder PCB.; Tue 11/12/19; Progress report.; Power up milestone.; Tue 11/19/19; Create enclosure.; Tue 11/26/19; Tue 12/3/19; Presentations due.; Create build instructions (README.md).; Wed 12/11/19; Start CENG355, group meeting.; Mon 1/6/20; specification.; Group integration.

1 | Choose project and meet with members. | 3 days | Tue 9/3/19 | Thu 9/5/19
7 | Add proof of purchase to blog. | 1 day | Wed 10/2/19 | Wed 10/2/19
9 | Show acquisitions and Check in meeting. | 1 day | Tue 10/8/19 | Tue 10/8/19
12 | Get PCB etched by sending Gerber file. | 10 days? | Sun 10/20/19 | Thu 10/31/19
13 | Create blog post about PCB design. | 2 days | Sun 10/20/19 | Mon 10/21/19
19 | Create blog post for soldering milestone. | 1 day | Tue 11/5/19 | Tue 11/5/19
25 | App, web, and database software requirements
27 | Group troubleshooting.
28 | Group project status update.
29 | Group physical enclosure complete.
30 | Project demonstration.
31 | Group presentations.
32 | Group final report due. | 1 day | Fri 4/17/20 | Fri 4/17/20
M | T | W | T | F | S | S
Sep 1, '19 | Sep 8, '19

Sep 8, '19; Sep 15, '19; Sep 22, '19; Sep 29, '19; Oct 6, '19; Oct 13, '19; Oct 20, '19

Oct 27, '19; Nov 3, '19; Nov 10, '19; Nov 17, '19; Nov 24, '19; Dec 1, '19

S | S | M | T | W | T | F | S | S | M | T | W | T | F | S | S | M | T | W | T | F | S | S | M | T | W | T | F | S | S | M | T | W | T | F | S | S | M | T | W | T | F | S | S | M
Dec 8, '19 | Dec 15, '19 | Dec 22, '19 | Dec 29, '19 | Jan 5, '20 | Jan 12, '20 | Jan 19, '20

T | W | T | F | S | S | M | T | W | T | F | S | S | M | T | W | T | F | S | S | M | T | W | T | F | S | S | M | T | W | T | F | S | S | M | T | W | T | F | S | S | M | T | W | T
Jan 19, '20 | Jan 26, '20 | Feb 2, '20 | Feb 9, '20 | Feb 16, '20 | Feb 23, '20 | Mar 1, '20

F | S | S | M | T | W | T | F | S | S | M | T | W | T | F | S | S | M | T | W | T | F | S | S | M | T | W | T | F | S | S | M | T | W | T | F | S | S | M | T | W | T | F | S | S | M
Mar 8, '20 | Mar 15, '20 | Mar 22, '20 | Mar 29, '20 | Apr 5, '20 | Apr 12, '20 | Apr 19, '20

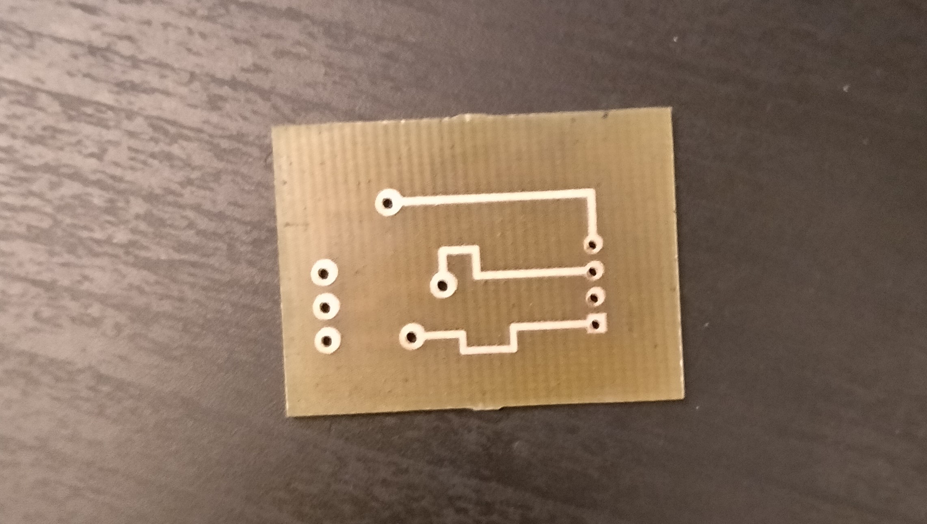
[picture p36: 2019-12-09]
Images/pcb_back_cropped.jpg

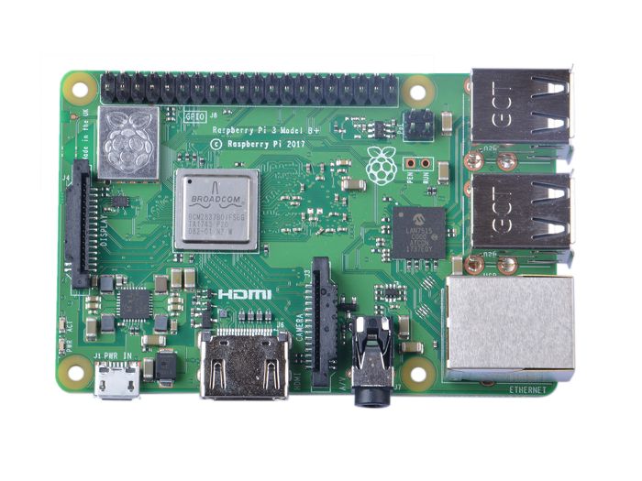
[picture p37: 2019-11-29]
Images/raspberrypi3b+.jpg

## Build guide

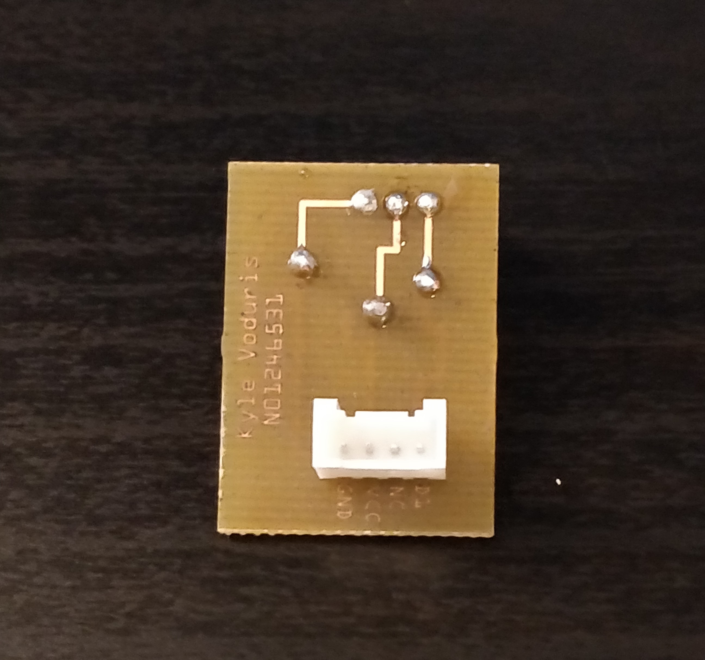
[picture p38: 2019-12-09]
Images/pcb_front_soldered_cropped.jpg

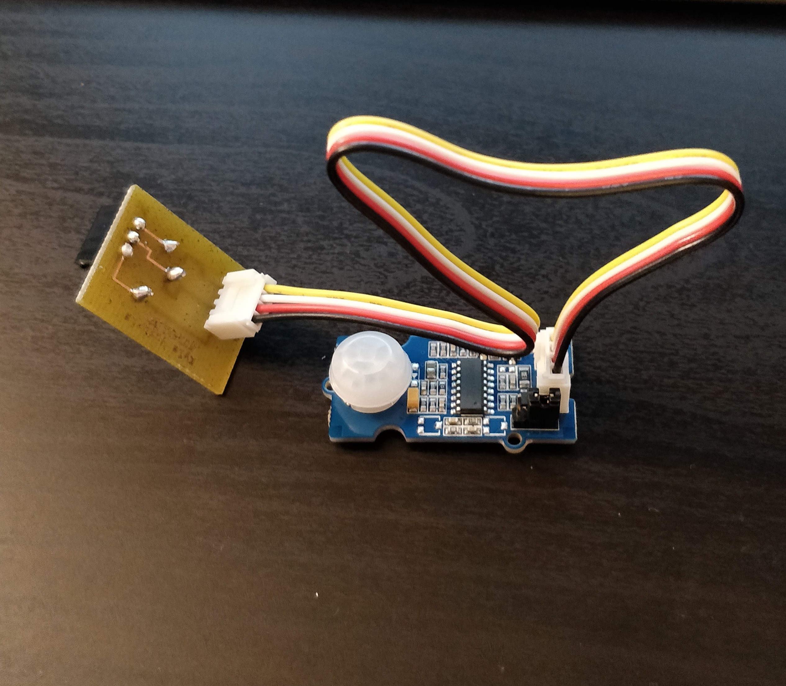
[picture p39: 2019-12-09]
Images/pcb_soldered_sensor_cropped.jpg

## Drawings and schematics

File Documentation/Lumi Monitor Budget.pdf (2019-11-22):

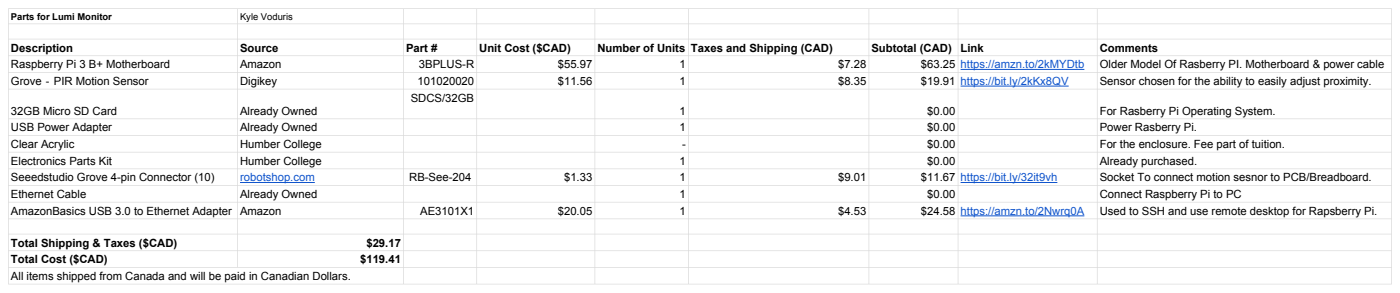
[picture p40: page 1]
Parts for Lumi Monitor; Kyle Voduris; Description; Source; Part #; Unit Cost ($CAD); Number of Units Taxes and Shipping (CAD); Subtotal (CAD) Link; Comments Raspberry Pi 3 B+ Motherboard; Amazon; 3BPLUS-R; $63.25 https://amzn.to/2kMYDtb; Older Model Of Rasberry PI. Motherboard & power cable Grove ‐ PIR Motion Sensor; Digikey; $19.91 https://bit.ly/2kKx8QV; Sensor chosen for the ability to easily adjust proximity.; 32GB Micro SD Card; Already Owned; SDCS/32GB; For Rasberry Pi Operating System.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

All items shipped from Canada and will be paid in Canadian Dollars.

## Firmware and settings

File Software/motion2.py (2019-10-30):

import RPi.GPIO as GPIO
import time

sensorPin = 12

GPIO.setmode(GPIO.BOARD)
GPIO.setup(sensorPin,GPIO.IN, pull_up_down=GPIO.PUD_UP)

prevState = False
currState = False

while True:
  time.sleep(0.1)
  prevState = currState
  currState = GPIO.input(sensorPin)
  if currState != prevState:
    newState = "HIGH" if currState else "LOW"
    print "GPIO pin %s is %s" % (sensorPin, newState)

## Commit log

2019-10-15 Uploaded Fritzing File aswell as PCB,Breadboard and Schematic views
    [LumiMonitor_MotionSensor.fzz]
2019-10-15 Edit PCB
    [LumiMonitor_MotionSensor.fzz, LumiMonitor_MotionSensor2.fzz]
2019-10-15 update pcb and schematic diagrams
    [LumiMonitor_MotionSensor2.fzz]
2019-10-27 Fixed and Updated PCB
    Create PIR Motion Sensor Part for breadboard view and adjusted pcb.
    [LumiMonitor_MotionSensor.fzz, LumiMonitor_MotionSensor2.fzz]
2019-10-27 Updated schematic and fzz
    [LumiMonitor_MotionSensor.fzz]
2019-10-30 added two test programs
    These programs test functionality of my PIR motion sensor
